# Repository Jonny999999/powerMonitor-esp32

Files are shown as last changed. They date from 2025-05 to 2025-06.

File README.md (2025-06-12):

# ESP32 PV Power Monitoring System

This project documents a system for monitoring photovoltaic (PV) power production and household power consumption using **ESP32** and **PZEM-004T** / **PZEM-016** power sensors, with data published over **MQTT**.

Included in this repo:

- Firmware for several ESP32 individually configured breakout boards, built with ESP-IDF 5.3
- Python utility for configuring PZEM modules over USB serial
- Hardware project for a custom UART ↔ RS485 interface board (KiCad) for a simple stripboard

---

## Dashboard Demo

The following screenshots show the resulting dashboard created using Node-RED where the sensor data is received via MQTT and stored in a database.
The charts visualize all sensor values across multiple inverters and locations.

### Live Chart View (Total sum, Active power, Current)

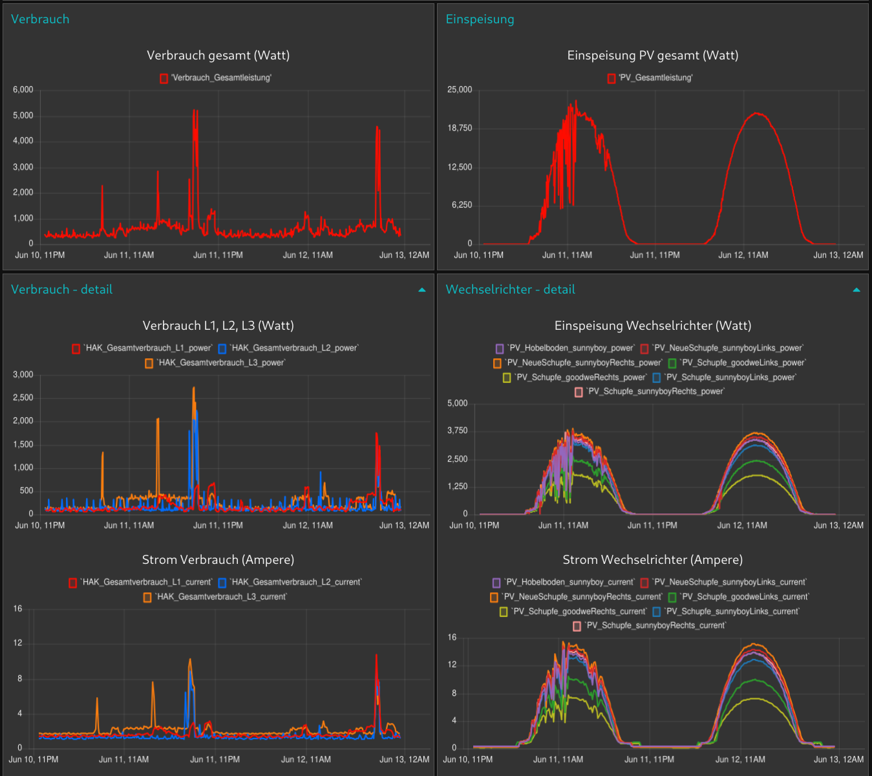
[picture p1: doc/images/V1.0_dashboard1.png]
Dashboard Part 1


---

### Live Chart View (Power factor, Voltage, Frequency)

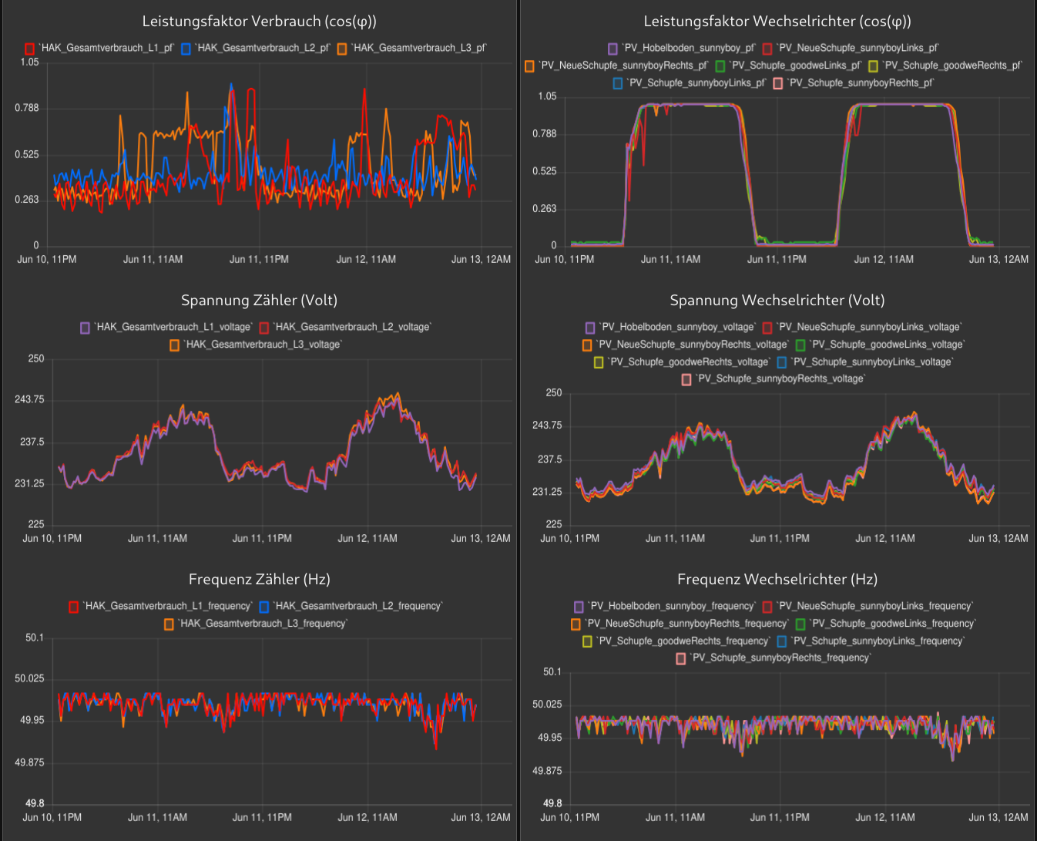
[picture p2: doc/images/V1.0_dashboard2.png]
Dashboard Part 2


---

## Hardware Setup

Below are a few example photos of the current wiring and hardware setup.

### 3x PZEM-003T measuring total consumption (main distribution board)

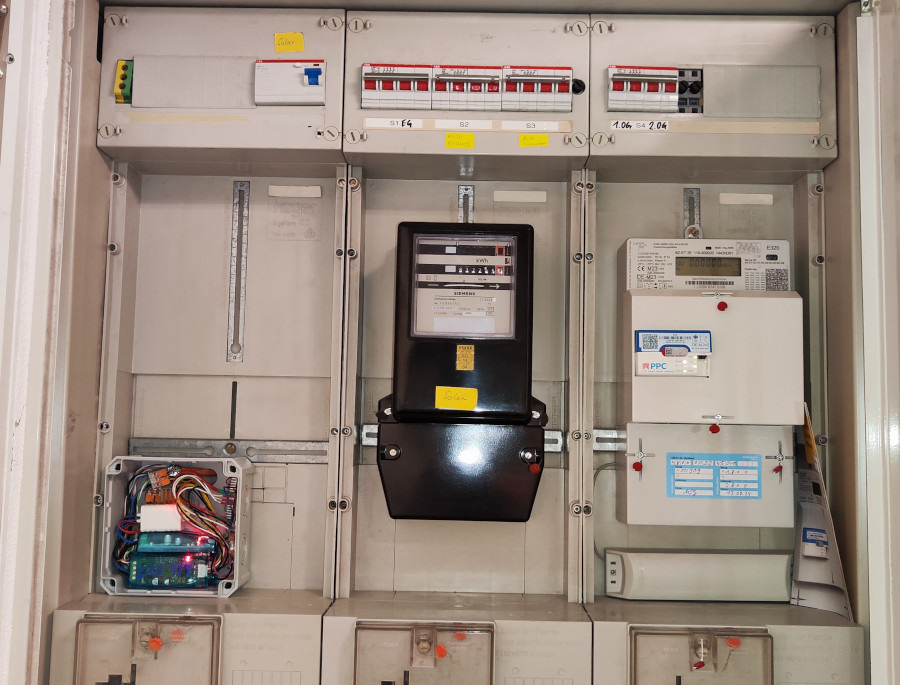
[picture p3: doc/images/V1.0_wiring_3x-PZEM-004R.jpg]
3x PZEM
  
Used for measuring total consumption of the entire building. One module for each phase (L1, L2, L3).

---

### Single PZEM-004T (inverter distribution box)

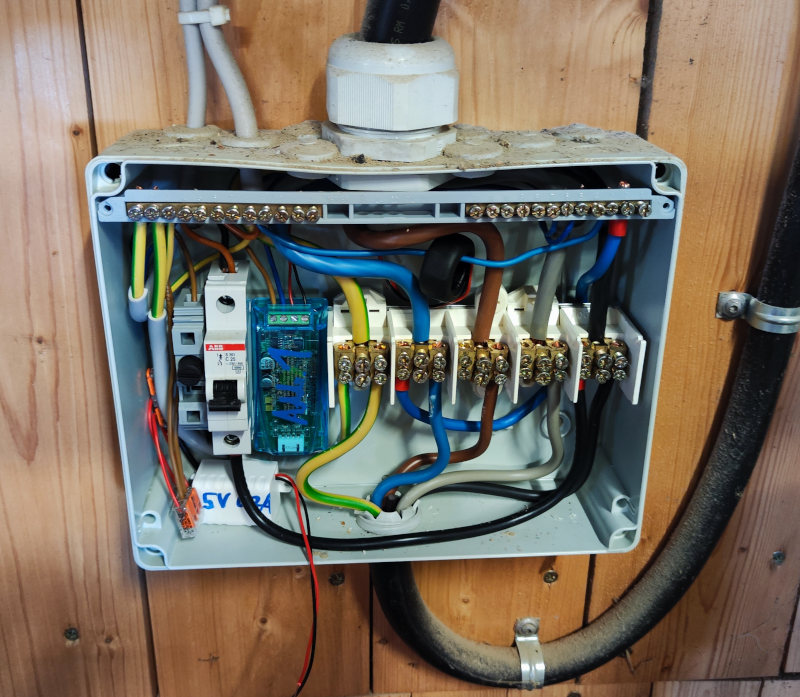
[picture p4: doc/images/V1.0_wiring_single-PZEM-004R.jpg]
Single PZEM
  
Each module is wired to one phase of a single inverter output.

---

### 2× PZEM-016 via RS485 (distribution box Remote inverters)

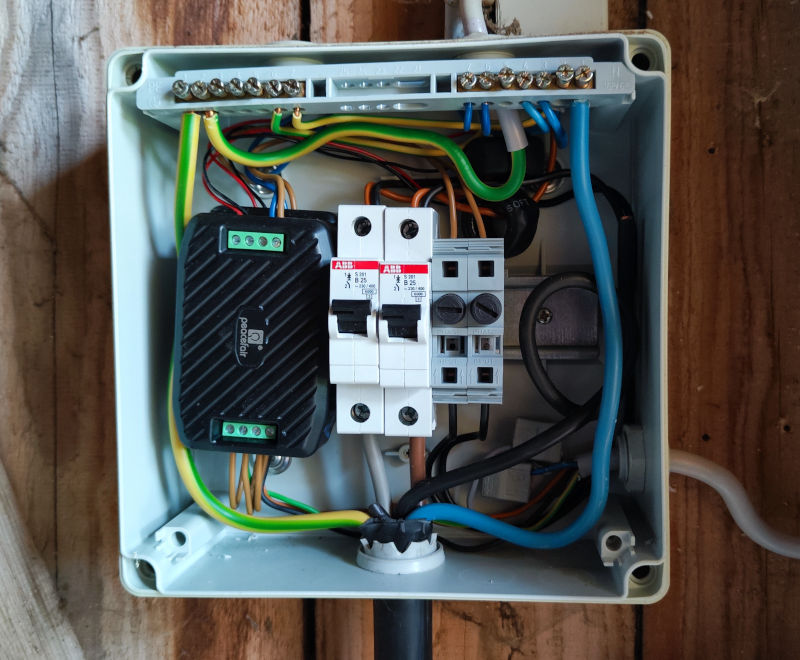
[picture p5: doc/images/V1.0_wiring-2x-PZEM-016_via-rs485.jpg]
2x PZEM-016
  
PZEM-016 modules connected via a shared RS485 bus and assigned separate Modbus addresses.  
On the other side of a ~30 m 5×1.5 mm² power cable, an ESP32 with a custom RS485-to-UART PCB receives the data and publishes it via MQTT.

---

## UART ↔ RS485 Interface (Custom PCB)

To interface the ESP32 with RS485-based PZEM-016 sensors, a small PCB based on the **MAX3485** transceiver was created.

- KiCad Project: [`hardware/UART-RS485_interface-board/`](hardware/UART-RS485_interface-board/)
- Schematic PDF: [`schematic.pdf`](hardware/UART-RS485_interface-board/export/schematic.pdf)

### Photo while testing

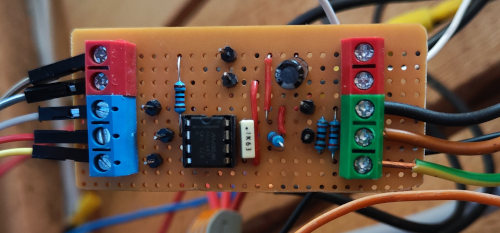
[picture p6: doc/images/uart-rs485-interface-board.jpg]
Interface PCB


---

## Firmware (ESP32)

Firmware for reading multiple PZEM modules and publishing the values via MQTT.  
Tested with ESP-IDF 5.3.

### Features

- Supports **PZEM-004T v3** (TTL UART) and **PZEM-016** (RS485)
- Configurable (per module):
  - Sensor address
  - GPIO pins (TX, RX, RTS)
  - MQTT topic prefix
  - Publish interval
  - Sensor type (TTL / RS485)
- Reads and publishes:
  - Voltage
  - Current
  - Power
  - Energy
  - Frequency
  - Power factor

### Build and Flash
Make sure ESP-IDF 5.3 is sourced:

```bash
. /opt/esp-idf-v5.3/v5.3/esp-idf/export.sh
cd esp32_power-monitor
idf.py build flash monitor
```

---

## Python Utility (`power-meter.py`)

Utility script for directly configuring and reading PZEM modules using a USB-to-Serial adapter.

### Functions

- Set or change Modbus address
- Reset energy counter
- Read live values

### Requirements

```bash
pip install pyserial
```

### Usage
1. Connect **RX/TX** of the FTDI adapter to the **TX/RX** of the PZEM module.
2. Plug the adapter into your PC.
3. Edit `pzem_tool.py`:
   - Set the correct serial port and slave ID
   - Uncomment the function you want to run (read, configure, reset)

Then run the script:

```bash
python3 pzem_tool.py
```

---

## Repository Structure

```
firmware/    # Several ESP-IDF projects for all instances running
hardware/UART-RS485_interface-board/   # KiCad project for interface PCB
doc/images/                            # photos and documentation
```

---

## Notes

- PZEM modules must be addressed and wired correctly (especially for RS485).
- Each PZEM sensor input should be fused and installed safely. Here i used a 200 mA 5x20 mm fuse for each module in the gray WAGO fuse holders for DIN rail.
- Wi-Fi credentials are configured via `main/credentials.h` which is not tracked in the repo.

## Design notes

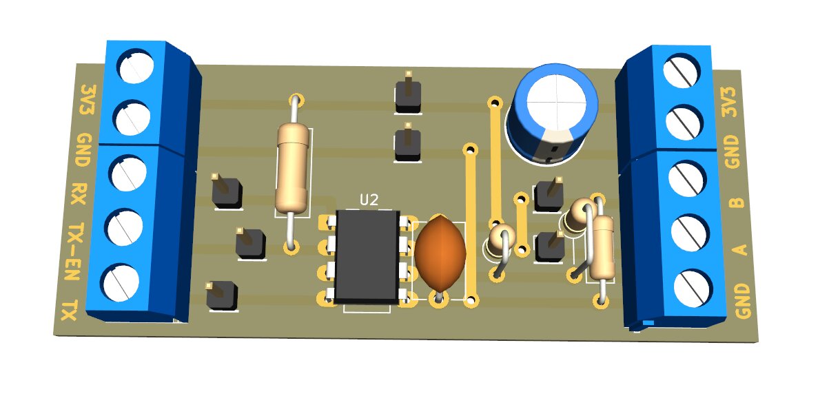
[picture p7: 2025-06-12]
hardware/UART-RS485_interface-board/export/3d.jpg

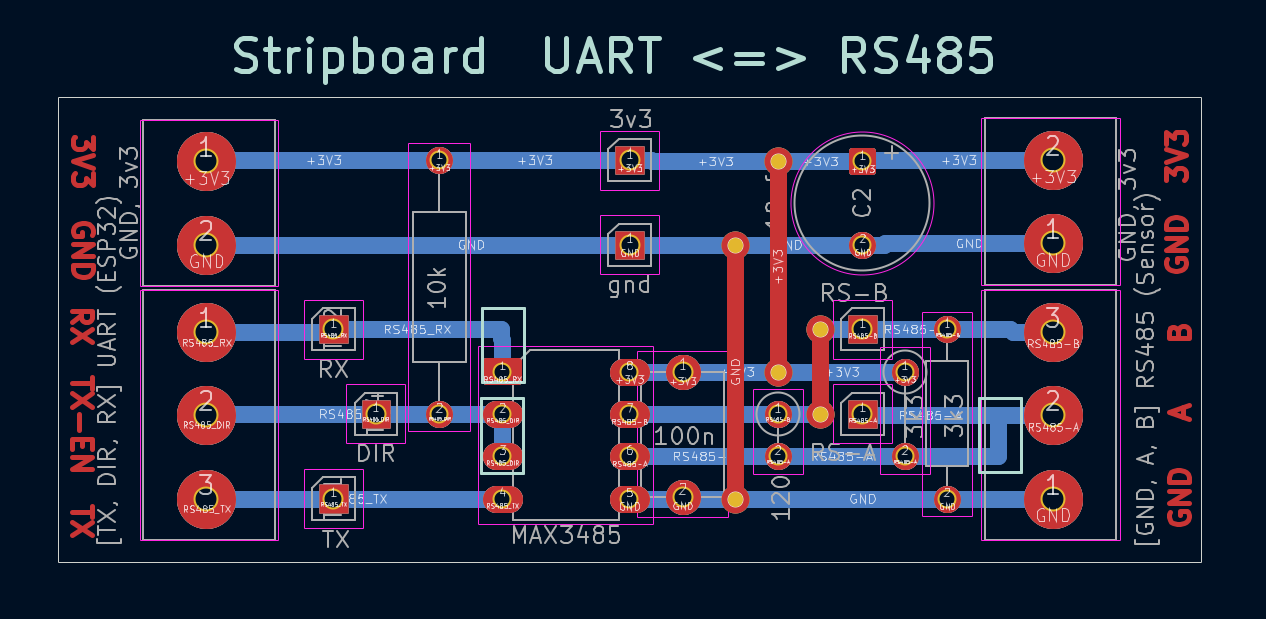
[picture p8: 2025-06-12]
hardware/UART-RS485_interface-board/export/layout.png

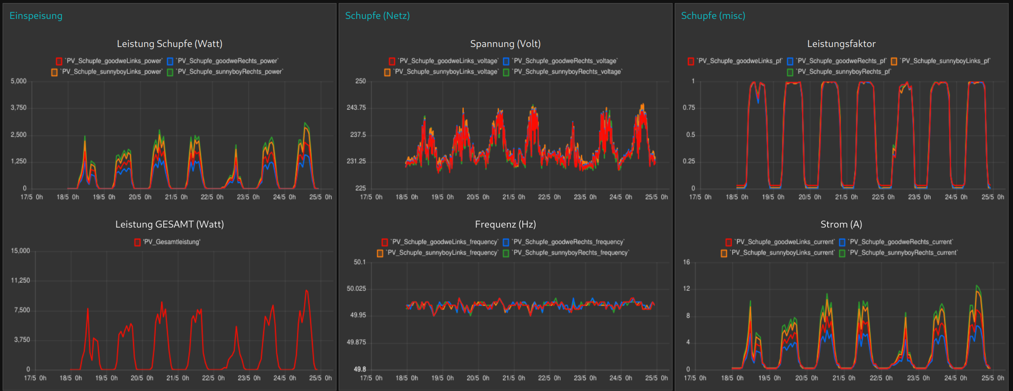
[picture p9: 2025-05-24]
doc/images/V0.1_dashboard.png

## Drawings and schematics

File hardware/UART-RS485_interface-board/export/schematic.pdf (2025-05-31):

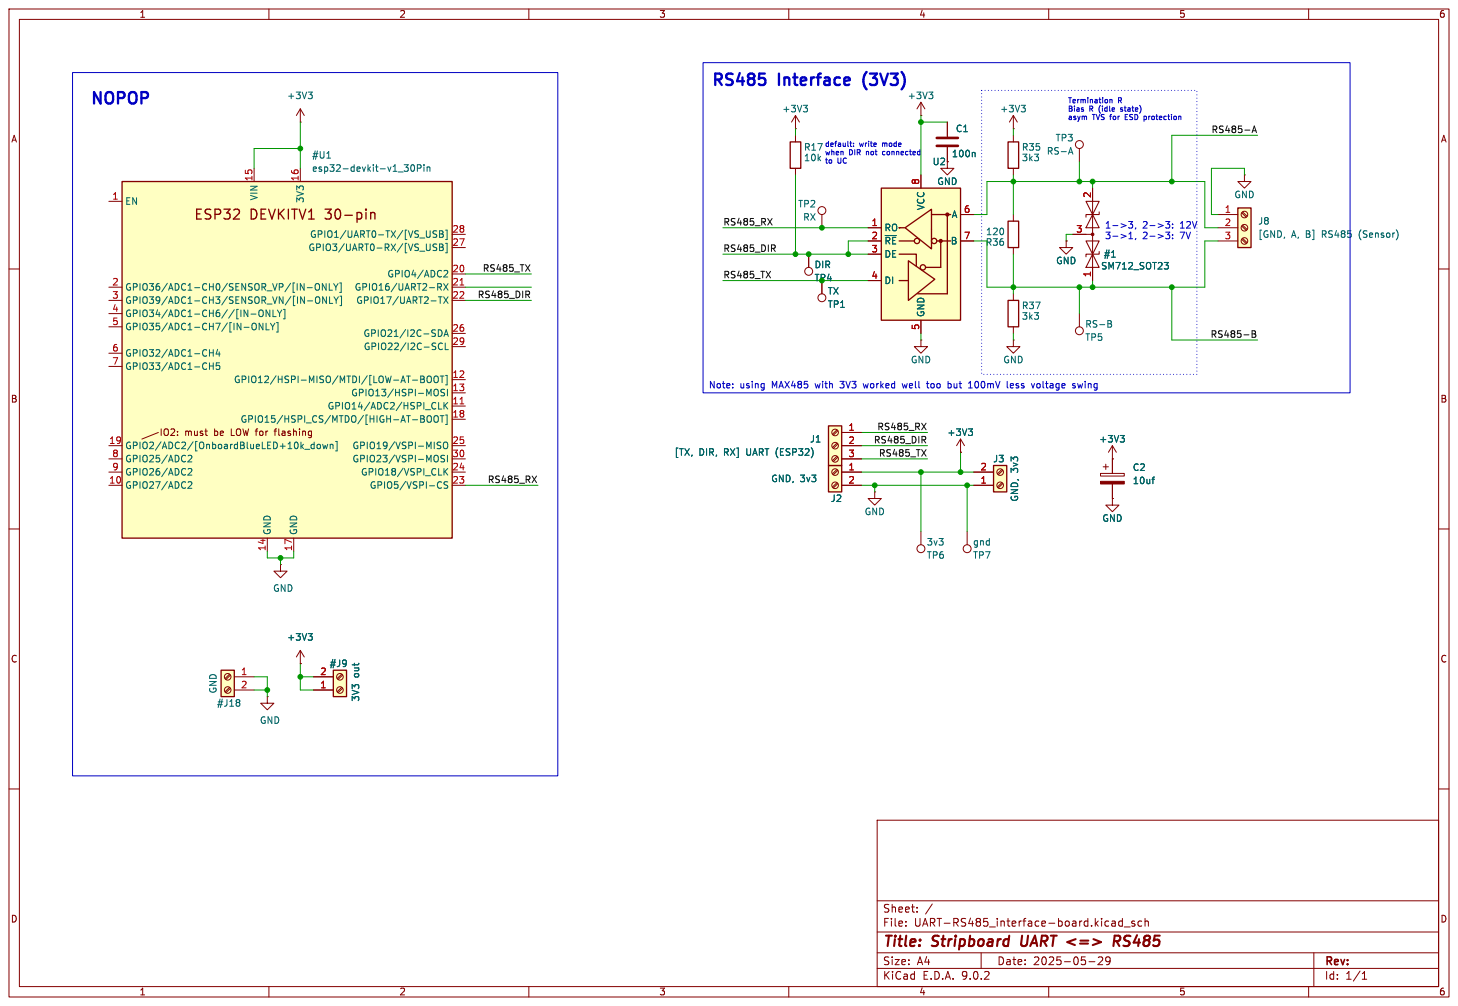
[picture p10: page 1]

Bias R (idle state) asym TVS for ESD protection NOPOP

IO2: must be LOW for flashing

File: UART-RS485_interface-board.kicad_sch Sheet: /

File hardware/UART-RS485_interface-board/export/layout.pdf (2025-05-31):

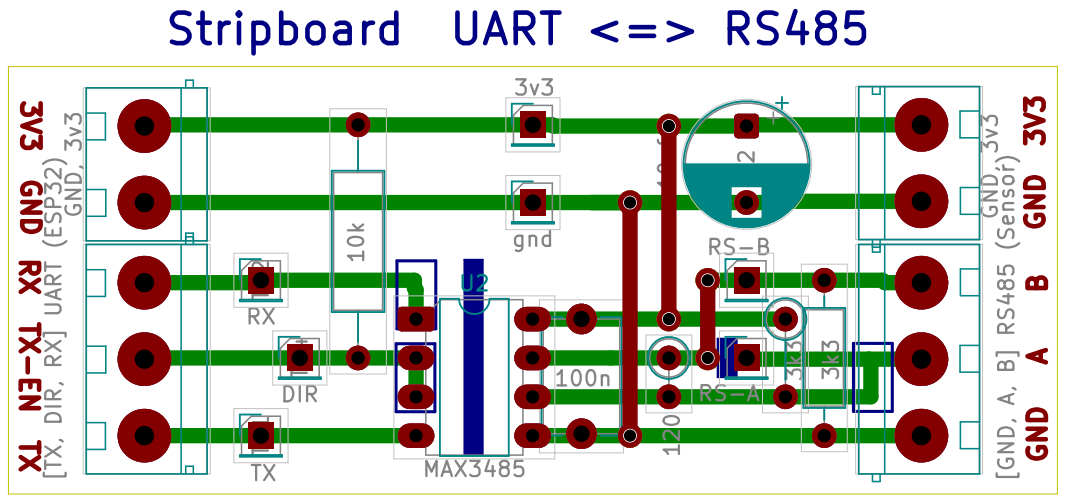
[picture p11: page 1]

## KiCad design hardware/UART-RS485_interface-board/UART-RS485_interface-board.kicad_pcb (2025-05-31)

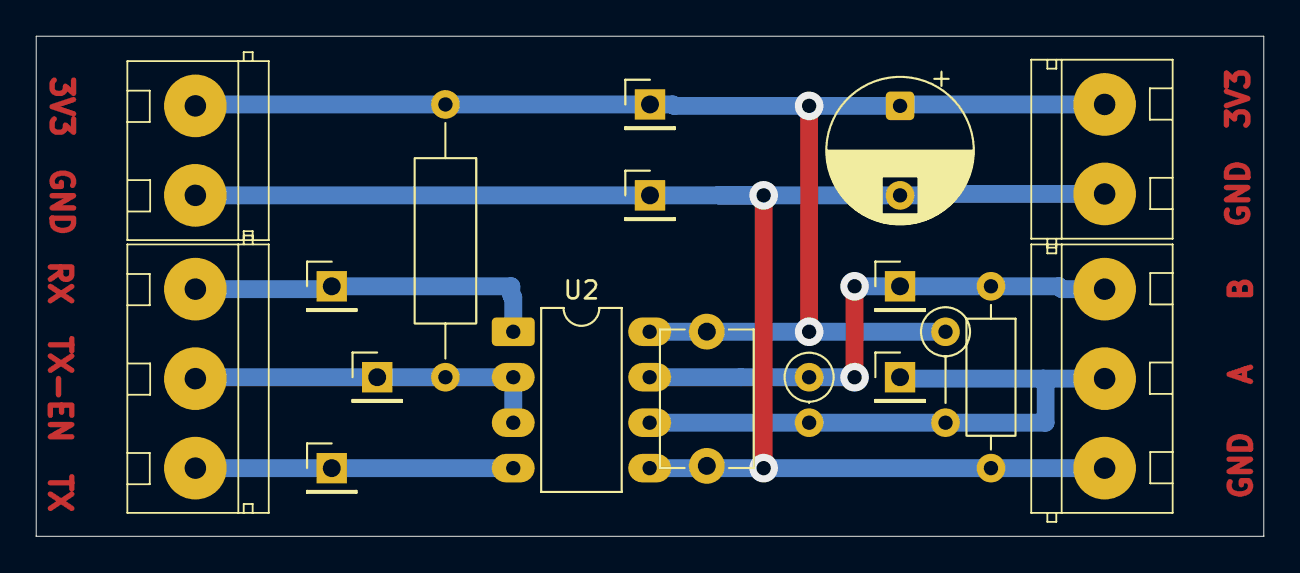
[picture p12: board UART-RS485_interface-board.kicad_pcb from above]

Board: 4 copper layers, 68.6 x 27.9 mm, 18 parts (0 on the bottom side), 7 nets.

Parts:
C1: 100n; C_Disc_D7.5mm_W5.0mm_P7.50mm
C2: 10uf; CP_Radial_D8.0mm_P5.00mm
J1: [TX, DIR, RX] UART (ESP32); ScrewTerminal_P5mm_3Pin_FP15x8
J2, J3: GND, 3v3; ScrewTerminal_P5mm_2Pin_FP10x8
J8: [GND, A, B] RS485 (Sensor); ScrewTerminal_P5mm_3Pin_FP15x8
R17: 10k; R_Axial_DIN0309_L9.0mm_D3.2mm_P15.24mm_Horizontal
R35: 3k3; R_Axial_DIN0207_L6.3mm_D2.5mm_P5.08mm_Vertical
R36: 120; R_Axial_DIN0207_L6.3mm_D2.5mm_P2.54mm_Vertical
R37: 3k3; R_Axial_DIN0207_L6.3mm_D2.5mm_P10.16mm_Horizontal
TP1: TX; PinHeader_1x01_P2.54mm_Vertical
TP2: RX; PinHeader_1x01_P2.54mm_Vertical
TP3: RS-A; PinHeader_1x01_P2.54mm_Vertical
TP4: DIR; PinHeader_1x01_P2.54mm_Vertical
TP5: RS-B; PinHeader_1x01_P2.54mm_Vertical
TP6: 3v3; PinHeader_1x01_P2.54mm_Vertical
TP7: gnd; PinHeader_1x01_P2.54mm_Vertical
U2: MAX3485; DIP-8_W7.62mm_LongPads

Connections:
+3V3: C1.1, C2.1, J2.1, J3.2, R17.1, R35.1, TP6.1, U2.8 (VCC)
/RS485-A: J8.2, R35.2, R36.2, TP3.1, U2.6 (A)
/RS485-B: J8.3, R36.1, R37.1, TP5.1, U2.7 (B)
/RS485_DIR: J1.2, R17.2, TP4.1, U2.2 (~RE), U2.3 (DE)
/RS485_RX: J1.1, TP2.1, U2.1 (RO)
/RS485_TX: J1.3, TP1.1, U2.4 (DI)
GND: C1.2, C2.2, J2.2, J3.1, J8.1, R37.2, TP7.1, U2.5 (GND)

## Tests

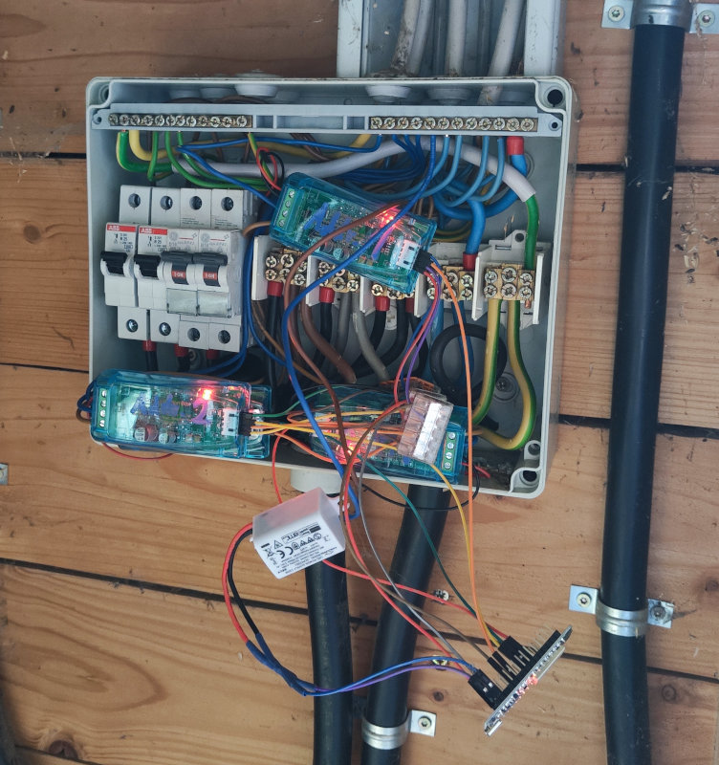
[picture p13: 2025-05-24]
doc/images/V0.1_temporary-test-setup.jpg

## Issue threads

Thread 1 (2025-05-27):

Powersave features useful?

Jonny999999, 2025-05-27:
- Sleep and only wake up briefly for publishing?
- worth it with current interval?

- turning off sensor supply will break Energy measurement

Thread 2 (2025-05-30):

energy reset not working with firmware

Jonny999999, 2025-05-30:
TODO: compare python code with firmware implementation, it fails when reading back its also not reset:

```
I (834) wifi:connected with BKA-network, aid = 4, channel 7, 40D, bssid = f8:d1:11:39:57:be
I (834) wifi:security: WPA2-PSK, phy: bgn, rssi: -57
I (844) wifi:pm start, type: 1

I (844) wifi:dp: 1, bi: 102400, li: 3, scale listen interval from 307200 us to 307200 us
I (854) esp_netif_handlers: sta ip: 10.0.0.83, mask: 255.255.0.0, gw: 10.0.0.1
I (854) WiFi: Got IP: 10.0.0.83
I (854) wifi:AP's beacon interval = 102400 us, DTIM period = 1
W (4794) app_main: Starting mqtt...
I (4794) common_mqtt: unhandled mqtt event 7 received
I (4804) wifi:<ba-add>idx:0 (ifx:0, f8:d1:11:39:57:be), tid:0, ssn:0, winSize:64
I (5564) common_mqtt: MQTT connected
W (6794) app_main: Starting publish task...
I (6794) PZ_INIT: Initializing UART
I (6794) uart: ALREADY NULL
I (6794) PZ_INIT: UART set pins, mode and install driver.
W (6804) common_PMon: RESET_ENERGY_OF_ALL_MODULES mode enabled -> resetting device 0
I (6804) main_task: Returned from app_main()
E (6854) common_PMon: [Sensor1 0x01] Failed to reset Energy, reading back anyways...
I (6924) PZ_GETVALUES: CRC check OK for GetValues()
I (6924) common_PMon: [Sensor1 0x01] verifying energy value... addr=0x01  read Energy=1.551
W (7224) common_PMon: Finished resetting all devices, stopping...
W (7224) common_PMon: Note: press reset button to reset again or disable this mode and flash again
I (11804) wifi:bcn_timeout,ap_probe_send_start
I (20824) wifi:bcn_timeout,ap_probe_send_start
I (29844) wifi:bcn_timeout,ap_probe_send_start
I (38854) wifi:bcn_timeout,ap_probe_send_start
I (47874) wifi:bcn_timeout,ap_probe_send_start
I (56894) wifi:bcn_timeout,ap_probe_send_start
I (80324) wifi:bcn_timeout,ap_probe_send_start
```

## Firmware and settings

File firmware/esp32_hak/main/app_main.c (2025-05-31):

#include "../custom_common/wifi_helper.h"
#include "../custom_common/mqtt_helper.h"
#include "../custom_common/powermon_task.h"
#include "../custom_common/config_types.h"

#include "nvs_flash.h"
#include "esp_log.h"



//===== CONFIG =====
#include "credentials.h" //actual wifi credentials outsourced
//#define WIFI_SSID "E14_mqtt-broker"
//#define WIFI_PASS "mqttdemo" // comment out if open wifi
#define WIFI_USE_STATIC_IP       1
#define WIFI_STATIC_IP_ADDR      "10.0.0.84"
#define WIFI_STATIC_NETMASK_ADDR "255.255.0.0"
#define WIFI_STATIC_GW_ADDR      "10.0.0.1"

#define UART_PORT UART_NUM_2
#define MQTT_BROKER_URI "mqtt://10.0.0.102"


// Local config for this ESP32 instance
// configure all connected PZEM-004T sensors
#define PUBLISH_INTERVAL_MS 30000 // interval all sensor data is read and published for each sensor
#define RETRY_INTERVAL_WHEN_READ_FAILED_MS 2000 //retry earlier than next interval when read failed
const ModbusSensor sensors[] = {
    // Note about connection: multiple sensors are connected to shared TX pin (master) 
    //   but each has its own RX pin to send to the master
    //   (shared RX would be shortcircuit since IDLE slaves pull active high)
    {
        .name = "Sensor L1",
        .modbus_addr = 1,
        .tx_pin = GPIO_NUM_16,
        .rx_pin = GPIO_NUM_17,
        .use_rs485 = false,
        .rs485_dir_pin = GPIO_NUM_NC,
        .mqtt_topic_prefix = "Sensordaten/HAK/Gesamtverbrauch/L1",
        .publish_interval_ms = PUBLISH_INTERVAL_MS,
    },
    {
        .name = "Sensor L2",
        .modbus_addr = 2,
        .tx_pin = GPIO_NUM_16,
        .rx_pin = GPIO_NUM_18,
        .use_rs485 = false,
        .rs485_dir_pin = GPIO_NUM_NC,
        .mqtt_topic_prefix = "Sensordaten/HAK/Gesamtverbrauch/L2",
        .publish_interval_ms = PUBLISH_INTERVAL_MS,
    },
    {
        .name = "Sensor L3",
        .modbus_addr = 3,
        .tx_pin = GPIO_NUM_16,
        .rx_pin = GPIO_NUM_19,
        .use_rs485 = false,
        .rs485_dir_pin = GPIO_NUM_NC,
        .mqtt_topic_prefix = "Sensordaten/HAK/Gesamtverbrauch/L3",
        .publish_interval_ms = PUBLISH_INTERVAL_MS,
    }
};


// Variables
#define TAG "app_main"



void app_main(void) {
    ESP_LOGI(TAG, "[APP] Startup..");
    nvs_flash_init();

    wifi_settings_t wifi = {
        .ssid = WIFI_SSID,
        .password = WIFI_PASS,
        .use_static_ip = WIFI_USE_STATIC_IP,
        .ip = WIFI_STATIC_IP_ADDR,
        .netmask = WIFI_STATIC_NETMASK_ADDR,
        .gateway = WIFI_STATIC_GW_ADDR
    };
    ESP_LOGW(TAG, "Starting wifi...");
    common_wifi_start(&wifi);
    vTaskDelay(pdMS_TO_TICKS(4000));


    ESP_LOGW(TAG, "Starting mqtt...");
    esp_mqtt_client_handle_t mqtt_client = common_mqtt_start(MQTT_BROKER_URI);
    vTaskDelay(pdMS_TO_TICKS(2000));


    PMonTaskConfig_t powerMonitor_TaskCfg = {
        .sensors = sensors,
        .sensor_count = sizeof(sensors) / sizeof(sensors[0]),
        .uart_port = UART_PORT,
        .mqtt_client = mqtt_client,
        .retry_interval_on_fail_ms = RETRY_INTERVAL_WHEN_READ_FAILED_MS
    };

    ESP_LOGW(TAG, "Starting publish task...");
    xTaskCreate((TaskFunction_t) common_PMonTask, "PowerMonitor", 4096, (void*) &powerMonitor_TaskCfg, 5, NULL);
}

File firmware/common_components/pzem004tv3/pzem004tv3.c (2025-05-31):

/**
 * Based on Espressif examples: https://github.com/espressif/esp-idf/blob/master/examples/peripherals/uart/uart_echo/main/uart_echo_example_main.c
 * And ported library from https://github.com/mandulaj/PZEM-004T-v30
 *
 */
#include "pzem004tv3.h"

/* Declare static func in .c file (linker warnings) */
static uint16_t crc16(const uint8_t *data, uint16_t len);

uint16_t _lastRead = 0; /* Last time values were updated */

/**
 * @brief Initialize the UART, configured via struct pzemSetup_t
 * @param pzSetup
 */
void PzemInit( pzem_setup_t *pzSetup )
{
    static const char *LOG_TAG = "PZ_INIT";

    ESP_LOGI( LOG_TAG, "Initializing UART" );

    const uart_port_t _uart_num = pzSetup->pzem_uart;
    const int uart_buffer_size = ( 1024 * 2 );

    /* Configure parameters of an UART driver,
     * communication pins and install the driver */
    uart_config_t uart_config = {
        .baud_rate  = PZ_BAUD_RATE,
        .data_bits  = UART_DATA_8_BITS,
        .parity     = UART_PARITY_DISABLE,
        .stop_bits  = UART_STOP_BITS_1,
        .flow_ctrl  = UART_HW_FLOWCTRL_DISABLE,
        .source_clk = UART_SCLK_APB,
    };

    // Try deleting the driver first (no-op if not installed) useful in case sensor/uart gets re-initialized with different config
    uart_driver_delete(_uart_num);

    int intr_alloc_flags = 0;

#if CONFIG_UART_ISR_IN_IRAM
    intr_alloc_flags = ESP_INTR_FLAG_IRAM;
#endif
#if CONFIG_UART_MORE_PRIO
    intr_alloc_flags = ESP_INTR_FLAG_LEVEL3;
#endif

    ESP_LOGI( LOG_TAG, "UART set pins, mode and install driver." );

    /* Install UART driver using an event queue here */
    ESP_ERROR_CHECK( uart_driver_install( _uart_num, uart_buffer_size, 0, 0, NULL, intr_alloc_flags ) );

    /* Configure UART parameters */
    ESP_ERROR_CHECK( uart_param_config( _uart_num, &uart_config ) );

    /* Set UART pins(TX: , RX: , RTS: -1, CTS: -1) */
    if (pzSetup->use_rs485) {
        // RS485 mode additionally requires RTS pin
        ESP_LOGI(LOG_TAG, "Configuring RS485 half-duplex mode with RTS on GPIO %d", pzSetup->rs485_dir_pin);
        ESP_ERROR_CHECK(uart_set_pin(
            _uart_num,
            pzSetup->pzem_tx_pin,
            pzSetup->pzem_rx_pin,
            pzSetup->rs485_dir_pin,  // RTS = DE/RE control
            UART_PIN_NO_CHANGE
        ));
        // enable half duplex mode so RTS pin is actually controlled
        ESP_ERROR_CHECK(uart_set_mode(_uart_num, UART_MODE_RS485_HALF_DUPLEX));

    } else {
        // TTL mode does not require DIR/RTS pin
        ESP_ERROR_CHECK(uart_set_pin(
            _uart_num,
            pzSetup->pzem_tx_pin,
            pzSetup->pzem_rx_pin,
            UART_PIN_NO_CHANGE,
            UART_PIN_NO_CHANGE
        ));
    }
}


/**
 * @brief Read response
 * @param pzSetup
 * @param resp
 * @param len
 * @return uint16_t
 */
uint16_t PzemReceive( pzem_setup_t *pzSetup, uint8_t *resp, uint16_t len )
{
    static const char *LOG_TAG = "PZ_RECEIVE";

    /* Configure a temporary buffer for the incoming data */
    uint16_t rxBytes = uart_read_bytes( pzSetup->pzem_uart, resp, len, pdMS_TO_TICKS( PZ_READ_TIMEOUT ) );

    if ( rxBytes > 0 ) {
        resp[ rxBytes ] = 0;
        ESP_LOGV( LOG_TAG, "Read %d  bytes: '%s'", rxBytes, resp );
        ESP_LOG_BUFFER_HEXDUMP( LOG_TAG, resp, rxBytes, ESP_LOG_VERBOSE );
    }

    return rxBytes;
}


/**
 * @brief In case you forgot the address
 * @param update
 * @return uint8_t
 */
uint8_t PzReadAddress( pzem_setup_t *pzSetup)
{
    static uint8_t response[ 7 ] = {0};
    memset(response, 0, sizeof(response));

    uint8_t addr = 0;

    /* Read 1 register */
    if ( !PzemSendCmd8( pzSetup, CMD_RHR, WREG_ADDR, 0x01, false, 0xFFFF ) ) {
        return INVALID_ADDRESS;
    }

    if ( PzemReceive( pzSetup, response, 7 ) != 7 ) { /* Something went wrong */
        return INVALID_ADDRESS;
    }

    /* Get the current address */
    addr = ( ( uint32_t ) response[ 3 ] << 8 | /* Raw address */
             ( uint32_t ) response[ 4 ] );

    return addr;
}

/**
 * @brief Change the default address of the pzem module
 * @return  true if succeeded
 */
bool PzSetAddress(pzem_setup_t *pzSetup, uint8_t new_addr)
{
    static const char *LOG_TAG = "PZ_SET_ADDR";

    // sanity check, see if address is valid
    if (new_addr < 0x01 || new_addr > 0xF7 ) {
        ESP_LOGI(LOG_TAG, "Address failed sanity check");
        return false;
    }

    if (pzSetup->pzem_addr  == new_addr) {
        ESP_LOGI(LOG_TAG, "New address is the same as the old address");
        return false;
    }

    // Write the new address to the register
    if (!PzemSendCmd8( pzSetup, CMD_WSR, WREG_ADDR, new_addr, true, 0xFFFF )) {
        ESP_LOGE(LOG_TAG, "Failed to set the new address !!!!");
        return false;
    }

    return true;
}

/**
 * @brief Energy counter does not reset af restart, this function can reset the counter
 * @param pzSetup
 * @return bool
 */
 bool PzResetEnergy( pzem_setup_t *pzSetup )
{
    static const char *LOG_TAG = "PZ_RESET_ENERGY";
    uint8_t buffer[4] = {0};  // 2 bytes + 2 bytes CRC
    uint8_t reply[4] = {0};

    buffer[0] = pzSetup->pzem_addr;  // same as slave_address
    buffer[1] = CMD_REST;            // 0x42
    // buffer[2]: CRC low byte
    // buffer[3]: CRC high byte

    PzemSetCRC(buffer, 4);           // CRC over first 2 bytes, write into buffer[2], buffer[3]

    if (uart_write_bytes(pzSetup->pzem_uart, buffer, 4) == -1) {
        ESP_LOGE(LOG_TAG, "Failed to write to sensor/UART !!");
        return false;
    }

    vTaskDelay(pdMS_TO_TICKS(100));  // wait a little, just like Python version

    // Read optional reply (usually nothing or echo)
    uint16_t length = PzemReceive(pzSetup, reply, sizeof(reply));

    ESP_LOGI(LOG_TAG, "Sent reset, got %d bytes reply", length);
    ESP_LOG_BUFFER_HEXDUMP(LOG_TAG, reply, length, ESP_LOG_INFO);

    return true;  // no specific response required
}
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

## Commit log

2025-05-01 Init - python script for reading sensor works
2025-05-01 Add functions for setting slave-addr + resetting power
    [power-meter.py]
2025-05-03 Add custom task to read multiple sensors, Adjust pzem init func to deinit UART first
2025-05-03 Add wifi+mqtt init, publish all data, Add actual 4 sensors
2025-05-24 Add wifi reconnect, Retry earlier when read failed
    [app_main.c, power-meter.py]
2025-05-25 Change project structure, Outsource common code (to support multiple boards)
2025-05-25 Add kicad Project for UART-RS485_interface-board
    [UART-RS485_interface-board.kicad_pcb, UART-RS485_interface-board.kicad_sch]
2025-05-29 UART-RS485 Stripboard: Adjust as actually soldered, fixes, add exports
    [UART-RS485_interface-board.kicad_pcb, UART-RS485_interface-board.kicad_sch]
2025-05-29 Adjust config (2x RS485 Sensors, IP, test-interval)
2025-05-30 Adjust config (1x TTL sensor, IP)
2025-05-30 Add mode for resetting energy to powermon_task, Set publish interval to 60s (all boards)
    [app_main.c, powermon_task.c]
2025-05-31 Fix energy reset func in pzem library (untested)
    [pzem004tv3.c]
2025-05-31 Fix RESET_ENERGY mode in pMonTask (also reset all sensors)
    [powermon_task.c]
2025-05-31 Create esp-idf project 'esp32_hak', Configure 3 sensors, 30s interval
2025-06-12 Add photos of wiring and board
2025-06-12 Update Readme: Add photos, Add pcb-project
